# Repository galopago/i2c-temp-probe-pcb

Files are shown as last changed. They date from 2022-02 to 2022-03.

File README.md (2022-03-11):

# PROBE STYLE I2C TEMPERATURE SENSOR PCB

Small circuit board, designed to be installed inside a metal tube or thermowell.

Read this in other languages: [Español](/assets/markdown/README.es.md)

Imagine this scenario: you have a bunch of I2C sensors tied to a bus (i.e. Humidity, pressure, light) and a waterproof temperature sensor is needed, the fastest option is to acquire one of the very popular OneWire type. This brings two big disadvantages:

* An additional GPIO pin (and wire!) is required, because I2C signals are incompatible with OneWire
* Additional libraries will be needed, protocols are very dissimilar in software too

There are very few waterproof temperature sensors in the market with a real I2C interface, but are not easy to obtain and are expensive. This document gives you some ideas on how to build your own waterproof I2C temperature sensor in an affordable way.

## Main features
* Open source
* Designed in KiCad PCB
* All source files available
* Gerber files available : single piece or 100x100mm panel
* Assorted flavors

## Printed circuit board

The PCB was designed to be as small as possible, but using SMD components that can be hand soldered. All pull-up resistors can be populated on the board. There are also onboard solder jumper pads for I2C address setup.

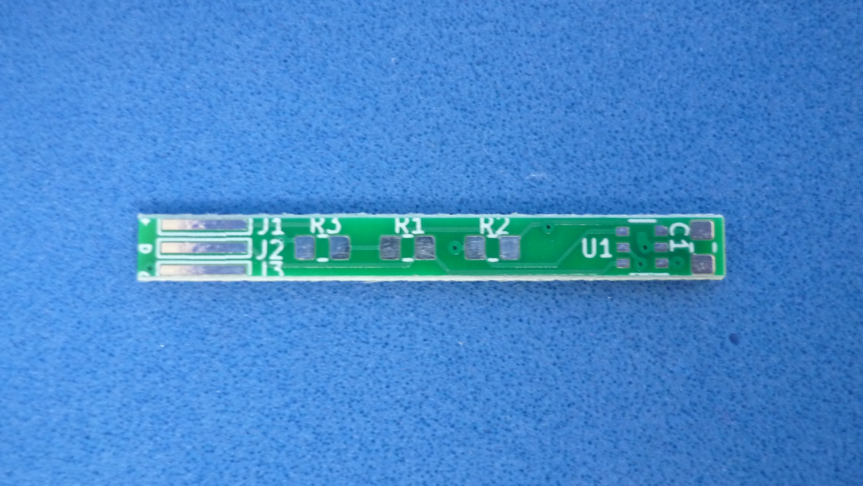
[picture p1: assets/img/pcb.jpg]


## Wiring

Multi conductor cable with 5 stranded wires used for VCC,GND,SDA,SCL and ALARM signals

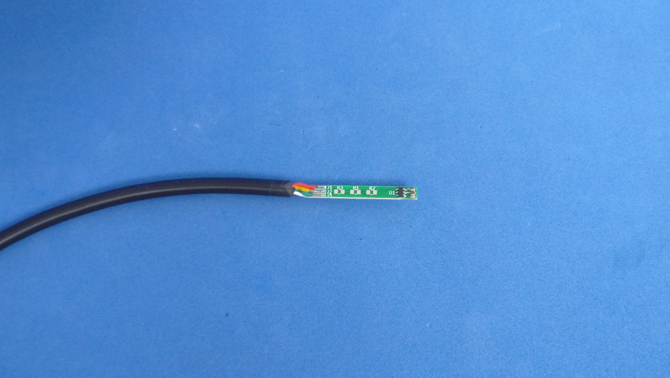
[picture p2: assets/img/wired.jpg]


## Waterproofing

The board could be fitted inside a stainless steel tube or thermowell. Some thermal silicone grease must be applied in the sensor zone, and epoxy glue near the cable input for sealing 

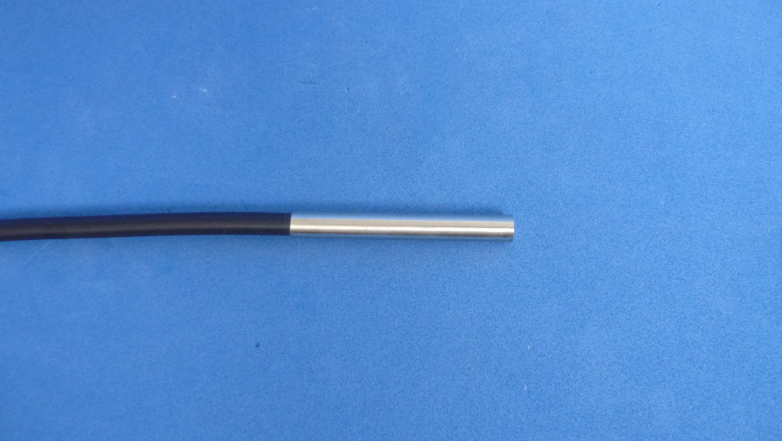
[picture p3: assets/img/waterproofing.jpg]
STEELTUBE


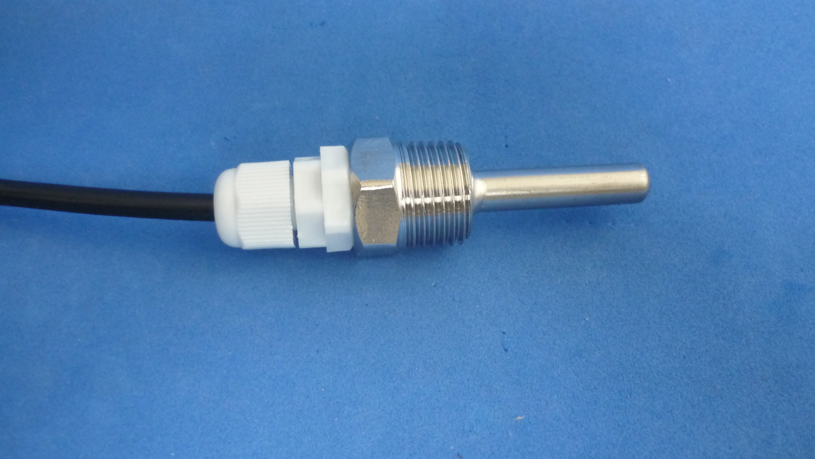
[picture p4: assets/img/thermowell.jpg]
THERMOWELL


## Versions

There are several board versions, each one with different sensor and PCB sizes

| SENSOR  | SIZE | LINK |
|---|---|---|
| LM75A |  5.5x35mm | [lm75A-probe-pcb](/lm75A-probe-pcb) |
| PCT2075 |  4.0x35mm | [pct2075-probe-pcb](/pct2075-probe-pcb)|

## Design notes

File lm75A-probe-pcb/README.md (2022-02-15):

# PROBE STYLE I2C TEMPERATURE SENSOR PCB

Small circuit board (5.5x35mm), based on [LM75A](assets/pdf/lm75a.pdf) chip, designed to be installed inside a metal tube or thermowell.

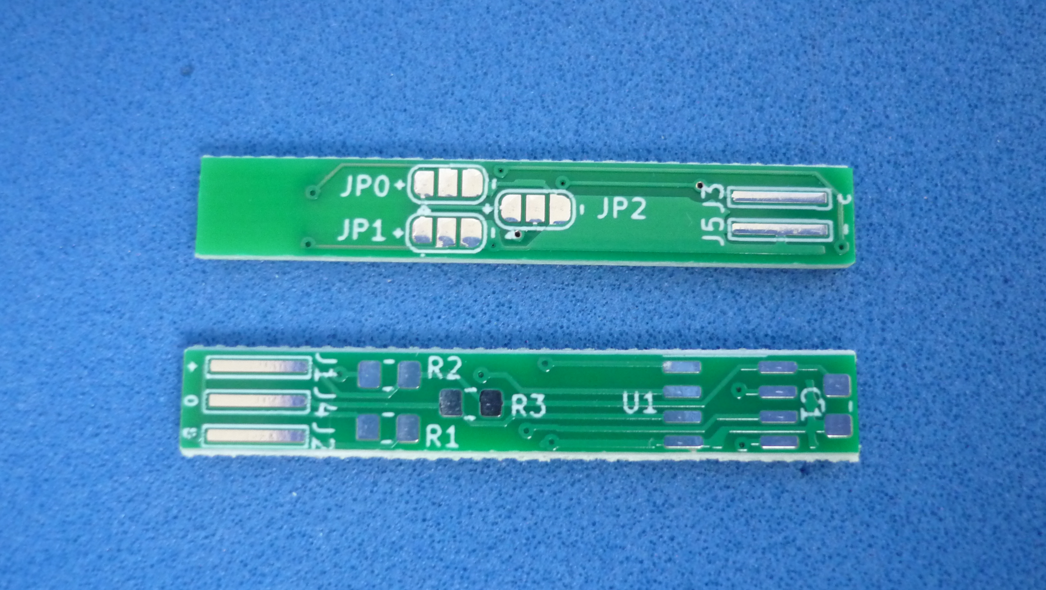
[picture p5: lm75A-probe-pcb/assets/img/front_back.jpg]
PCB_FRONT_BACK


## How to use this repository

The PCB was developed in KiCad V5.1,

## Directory structure

* The root folder contains template KiCad files: project, schematic and PCB 
* /modules folder contains additional footprints needed to edit printed circuit board
* /gerber folder contains ready to manufacture files.
* /assets folder contains support files for reade.md

## Board pinout

BOARD_PINOUT

## Panelized boards

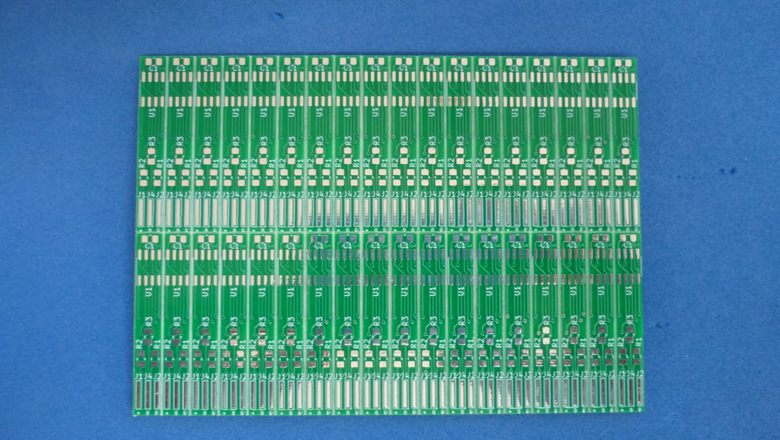
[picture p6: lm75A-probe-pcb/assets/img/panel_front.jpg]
PCB_PANEL


## Wired board

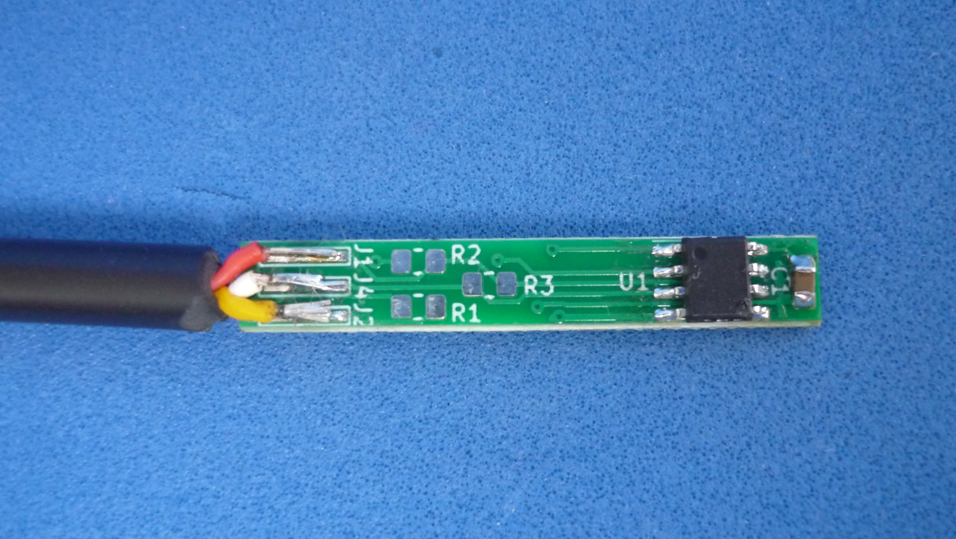
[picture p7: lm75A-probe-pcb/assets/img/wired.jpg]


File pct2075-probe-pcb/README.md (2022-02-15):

# PROBE STYLE I2C TEMPERATURE SENSOR PCB

Small circuit board (4.0x35mm), based on [PCT2074](assets/pdf/PCT2075.pdf) chip, designed to be installed inside a metal tube or thermowell.

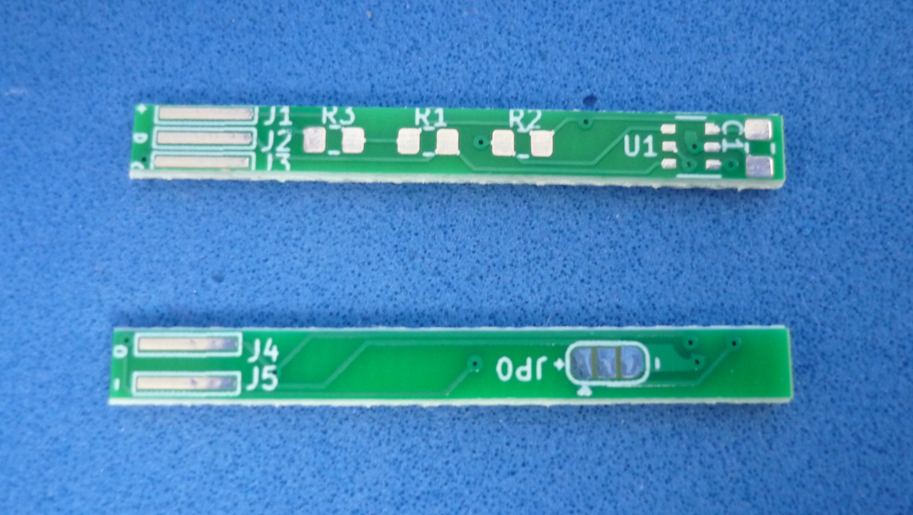
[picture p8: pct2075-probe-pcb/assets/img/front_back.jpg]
PCB_FRONT_BACK


## How to use this repository

The PCB was developed in KiCad V5.1,

## Directory structure

* The root folder contains template KiCad files: project, schematic and PCB 
* /modules folder contains additional footprints needed to edit printed circuit board
* /library folder contains additional footprints needed to edit schematic
* /gerber folder contains ready to manufacture files.
* /assets folder contains support files for reade.md

## Board pinout

BOARD_PINOUT

## Panelized boards

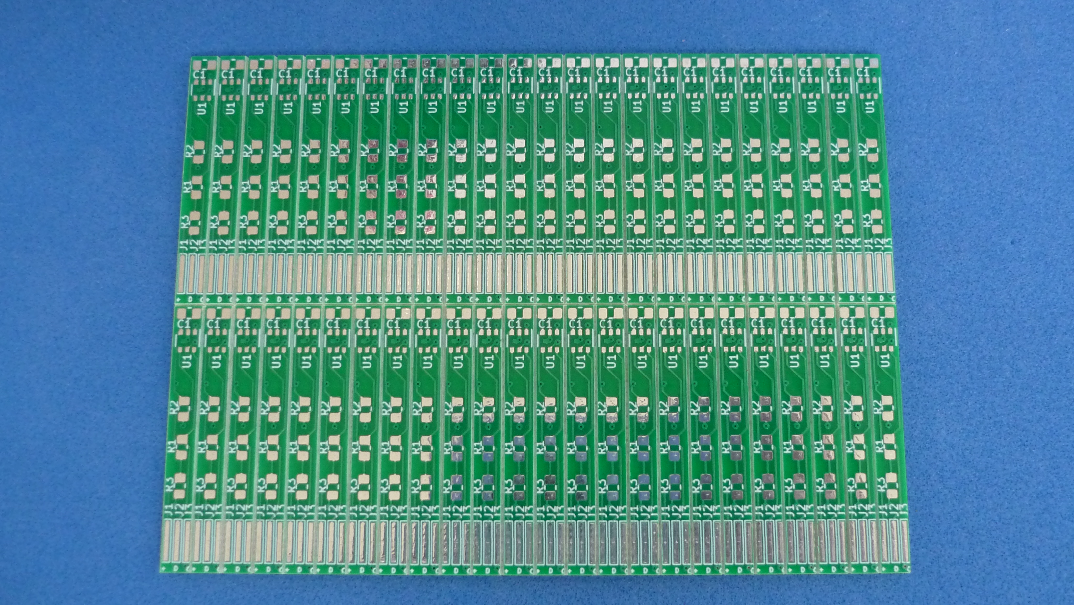
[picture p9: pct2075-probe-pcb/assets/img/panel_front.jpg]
PCB_PANEL


## Wired board

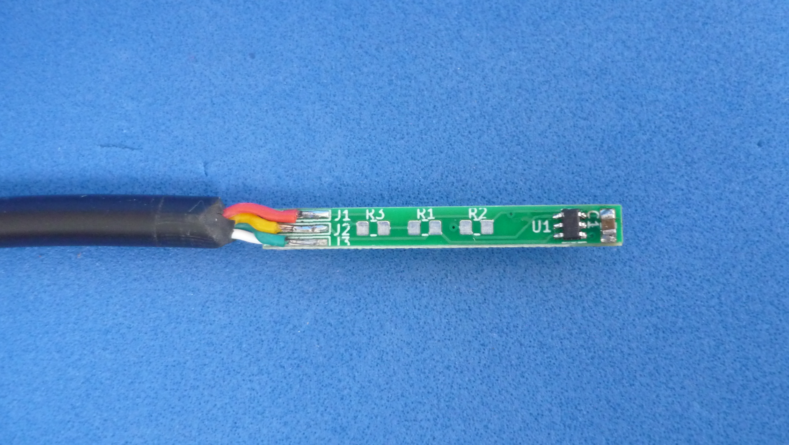
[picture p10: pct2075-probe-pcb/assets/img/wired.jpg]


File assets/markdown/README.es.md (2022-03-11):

# PCB PARA SENSOR DE TEMPERATURA I2C TIPO SONDA

Circuito impreso de pequeñas dimensiones, pensado para ser usado como sonda dentro de un tubo de acero inoxidable o termopozo. 

Lea esto en otros idiomas: [English](../../README.md)

Cuando se tiene un conjunto de sensores en un bus I2C, por ejemplo: Humedad, iluminacion, presion, etc. y se requiere agregar un sensor de temperatura a prueba de agua para fluidos, la opcion mas rapida es emplear dispositivos del tipo OneWire, bastante populares en el mercado. Esto tiene 2 inconvenientes:

* Se requiere un pin GPIO adicional para el sensor OneWire, pues estos son incompatibles con las señales I2C
* Se requieren librerias adicionales, pues en la capa de software los protocolos son muy diferentes

Existen algunos sensores de temperatura a prueba de agua con interfaz I2C real, sin embargo, no son tan faciles de conseguir, ni tan economicos como los OneWire. Este documento pretende dar algunas ideas de como construir tu propio sensor de temperatura I2C a prueba de agua a un precio razonable.

## Generalidades

* Codigo abierto
* Diseñado en KiCad PCB
* Disponibilidad de todos los archivos fuentes
* Archivos gerber listos para enviar a fabricar: una unidad o panelizados en area de 100x100mm
* Sabores surtidos

## El circuito impreso

La tarjeta se diseño para que tenga menor tamaño posible, pero usando componentes de montaje superficial que puedan ser soldados a mano. En la tarjeta pueden ser montados los resistores de pull-up y ademas hay un jumpers de configuracion mediante puente de soldadura para cambiar la direccion I2C del sensor.

MODULE

## Cableado

Se uso un cable recubierto multihilos de 5 conductores: VCC,GND,SDA,SCL y ALARMA.

MODULE

## Impermeabilizacion

La tarjeta puede instalarse dentro de un tubo metalico de acero inoxidable o dentro de un termopozo. Se requerira un poco de silicona conductora de calor en el area del sensor y pegamento epoxico para sellar y fijar el cable en la boca del tubo

TUBOACERO

THERMOPOZO

## Versiones

Existen varias versiones de tarjetas, cada una con un sensor de temperatura y dimensiones diferentes:

| SENSOR  | DIMENSIONES | ENLACE |
|---|---|---|
| LM75A |  5.5x35mm | [lm75A-probe-pcb](/lm75A-probe-pcb) |
| PCT2075 |  4.0x35mm | [pct2075-probe-pcb](/pct2075-probe-pcb)|

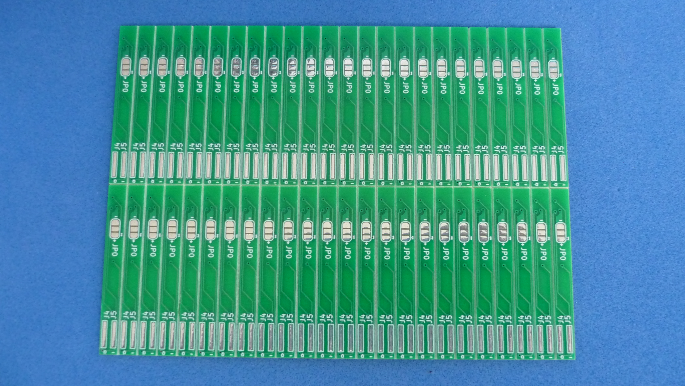
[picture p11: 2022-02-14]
pct2075-probe-pcb/assets/img/panel_back.jpg

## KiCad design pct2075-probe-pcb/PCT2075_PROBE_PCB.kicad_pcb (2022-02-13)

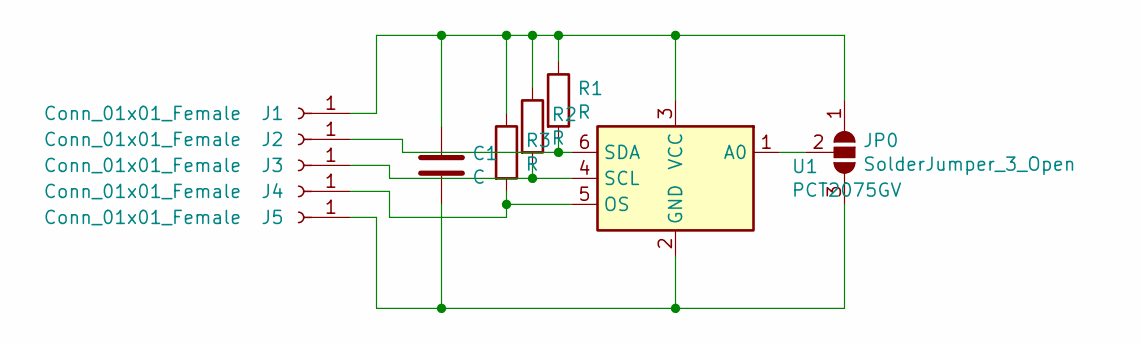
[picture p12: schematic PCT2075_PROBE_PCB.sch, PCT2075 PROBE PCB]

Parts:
C1: C; C_0805_2012Metric_Pad1.15x1.40mm_HandSolder
J1, J2, J3, J4, J5: Conn_01x01_Female; StrandedWire_Pad_0.6x5.0mm
JP0: SolderJumper_3_Open; SolderJumper-3_P1.3mm_Open_RoundedPad1.0x1.5mm
R1, R2, R3: R; R_0805_2012Metric_Pad1.15x1.40mm_HandSolder
U1: PCT2075GV; TSOP-6_1.65x3.05mm_P0.95mm

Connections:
unnamed: C1.1, J1.1, JP0.1 (A), R1.1, R2.1, R3.1, U1.3 (VCC)
unnamed: C1.2, J5.1, JP0.3 (B), U1.2 (GND)
unnamed: J2.1, R1.2, U1.6 (SDA)
unnamed: J3.1, R2.2, U1.4 (SCL)
unnamed: J4.1, R3.2, U1.5 (OS)
unnamed: JP0.2 (C), U1.1 (A0)

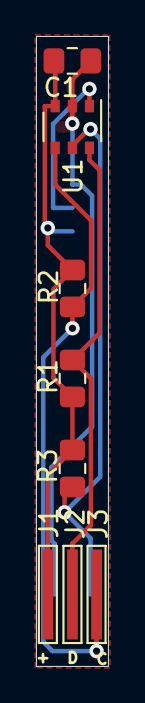
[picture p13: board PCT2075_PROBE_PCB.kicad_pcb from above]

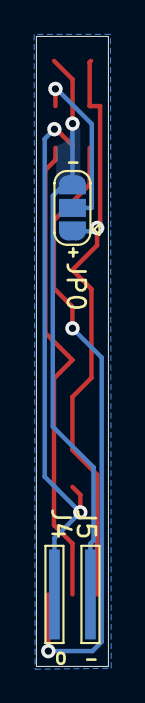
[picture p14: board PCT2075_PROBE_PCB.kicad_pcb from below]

Board: 2 copper layers, 4.0 x 35.0 mm, 11 parts (3 on the bottom side), 6 nets.

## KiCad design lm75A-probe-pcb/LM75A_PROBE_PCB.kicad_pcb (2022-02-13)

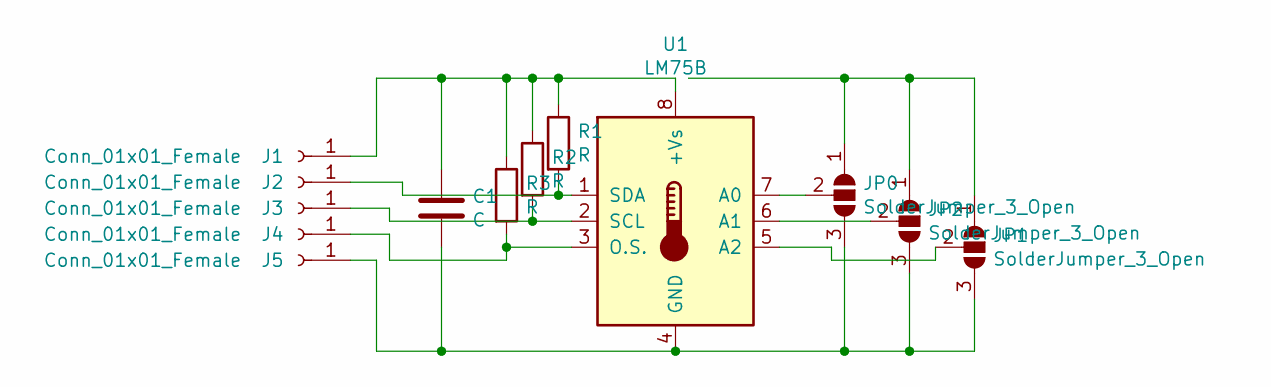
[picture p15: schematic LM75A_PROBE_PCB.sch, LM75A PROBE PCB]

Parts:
C1: C; C_0805_2012Metric_Pad1.15x1.40mm_HandSolder
J1, J2, J3, J4, J5: Conn_01x01_Female; StrandedWire_Pad_0.6x5.0mm
JP0, JP1, JP2: SolderJumper_3_Open; SolderJumper-3_P1.3mm_Open_RoundedPad1.0x1.5mm
R1, R2, R3: R; R_0805_2012Metric_Pad1.15x1.40mm_HandSolder
U1: LM75B; SOIC-8_3.9x4.9mm_P1.27mm

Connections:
unnamed: C1.1, J1.1, R1.1, R2.1, R3.1, U1.8 (+Vs)
unnamed: C1.2, J5.1, JP0.3 (B), JP1.3 (B), JP2.3 (B), U1.4 (GND)
unnamed: J2.1, R1.2, U1.1 (SDA)
unnamed: J3.1, R2.2, U1.2 (SCL)
unnamed: J4.1, R3.2, U1.3 (O.S.)
unnamed: JP0.1 (A), JP1.1 (A), JP2.1 (A)
unnamed: JP0.2 (C), U1.7 (A0)
unnamed: JP1.2 (C), U1.5 (A2)
unnamed: JP2.2 (C), U1.6 (A1)

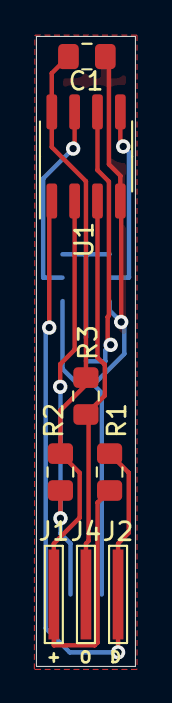
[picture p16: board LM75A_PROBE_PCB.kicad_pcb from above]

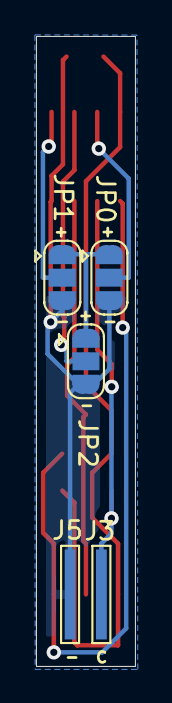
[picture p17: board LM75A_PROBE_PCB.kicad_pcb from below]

Board: 2 copper layers, 5.5 x 35.0 mm, 13 parts (5 on the bottom side), 9 nets.

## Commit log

2022-02-13 unified folders
    [LM75A_PROBE_PANEL-B_Cu-B_Cu.gbr, LM75A_PROBE_PANEL-B_Mask.gbr, LM75A_PROBE_PANEL-B_SilkS.gbr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]
2022-02-15 temp probe finished
2022-03-01 doc:(I2C_TEMP_PROBE ROOT)thermowell add pic
2022-03-11 doc:(i2c-temp-probe-pcb ROOT)renamed repo,folder changed links
    [LM75A_PROBE_PANEL-B_Cu-B_Cu.gbr, LM75A_PROBE_PANEL-B_Mask.gbr, LM75A_PROBE_PANEL-B_SilkS.gbr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]
2022-03-11 doc:(i2c-temp-probe-pcb ROOT)renamed repo,folder changed links+
    [PCT2075_PROBE_PCB-B_Cu.gbr, PCT2075_PROBE_PCB-B_Mask.gbr, PCT2075_PROBE_PCB-B_SilkS.gbr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]
2022-03-15 doc:(i2c-temp-probe-pcb root)license
